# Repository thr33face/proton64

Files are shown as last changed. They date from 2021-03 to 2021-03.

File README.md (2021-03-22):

# Proton-64 - C64/VIC20 keyboard to USB conversion

A case designed to house a standard, unmodified C64 (or VIC20) keyboard and QMK Proton C. Keyboard is at a 9° angle.

Bottom plate has one hole to expose the Proton C's button for easy firmware updates without the need for key combos/macros.

The case is held together by 9 M2x5 screws.

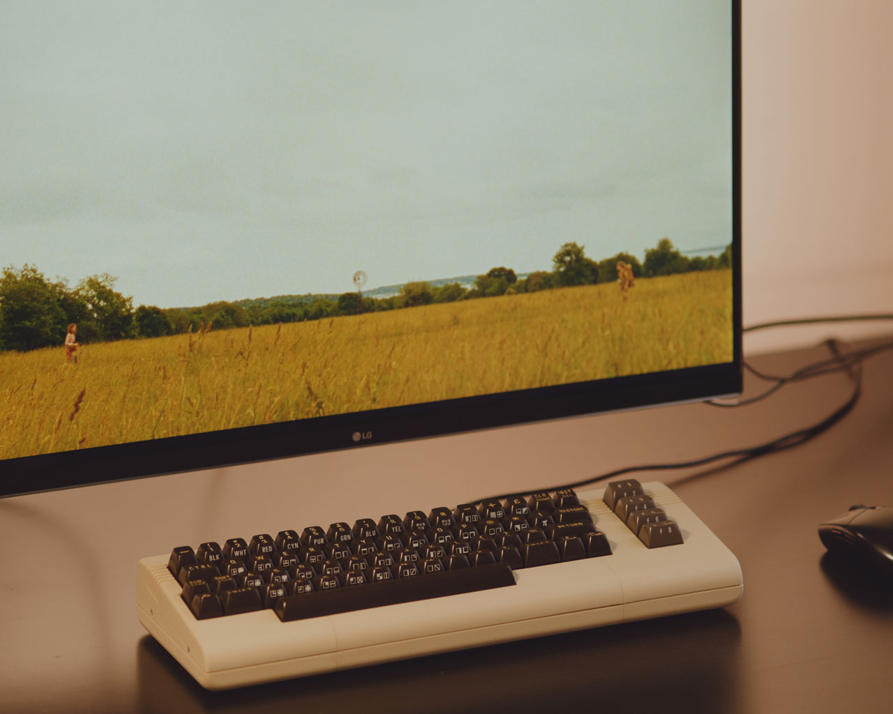
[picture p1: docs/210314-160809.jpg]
keyboard and monitor

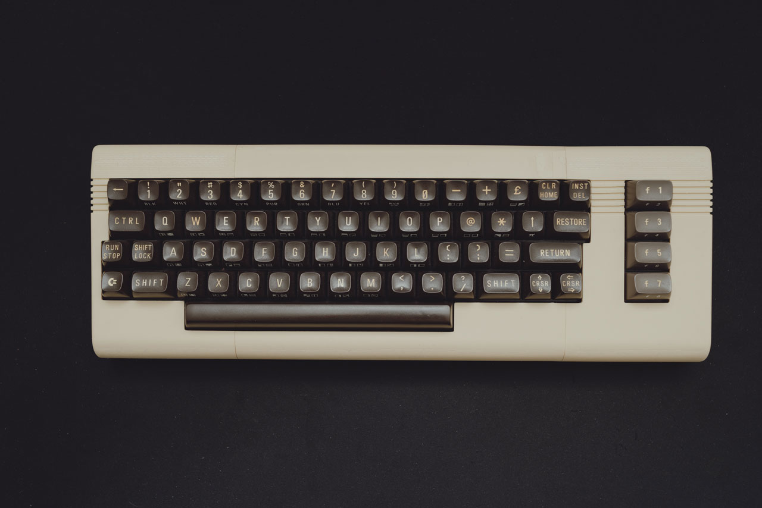
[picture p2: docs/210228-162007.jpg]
top shot


Depending on your printer and build size limitations you will have to cut the model into several pieces and join them somehow.
For my print I split the design by 3 horizontally and joined the pieces using CA-glue as well as 'welding' single layer PLA sheets over the joints. 

My recommendation is to add rubber feet to the 4 bottom corners.

Also, if you're not using a QMK Proton C you need to design your own IO-plate and modify the mounting/hold-down mechanism ('X' in bottom plate) to fit your specific controller. 

## Design goals ##
- no modifications to original keyboard
- capture design language of breadbin C64
- comfortable, usable angle without adjustment possibilities (original C64 wasn't adjustable)
- print in material simulating UV damage

## Some info about the print/build ##
**Modeled in:** Fusion 360

**Slicer:** Cura

**Printer:** Creality Ender 3 Pro (stock) @ 0.12mm

**Material:** Midori PLA (Beige RAL1014) - 200 °C

**Post Processing:** sanding and matte clear coat

**C64 keyboard manuf. year:** 1984

## Layers compared to original layout ##
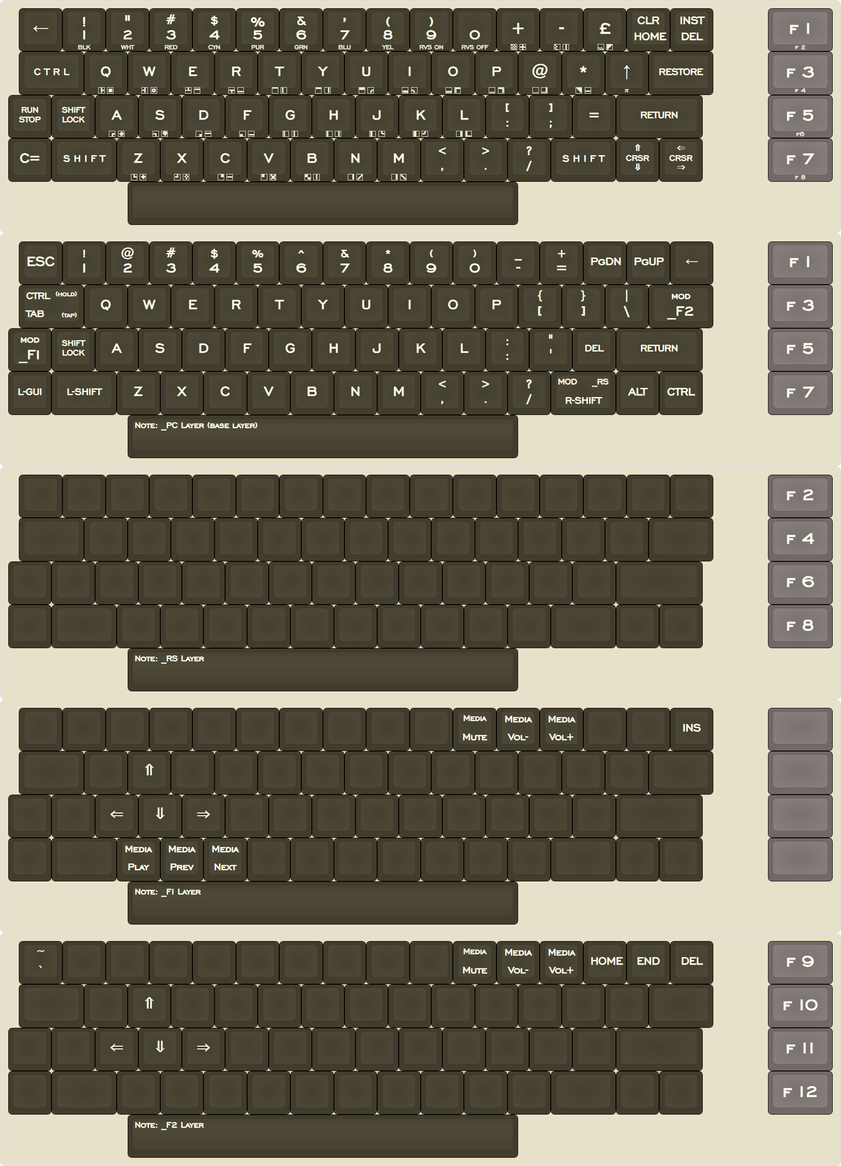
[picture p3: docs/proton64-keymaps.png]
keymap and layers


## More images ##
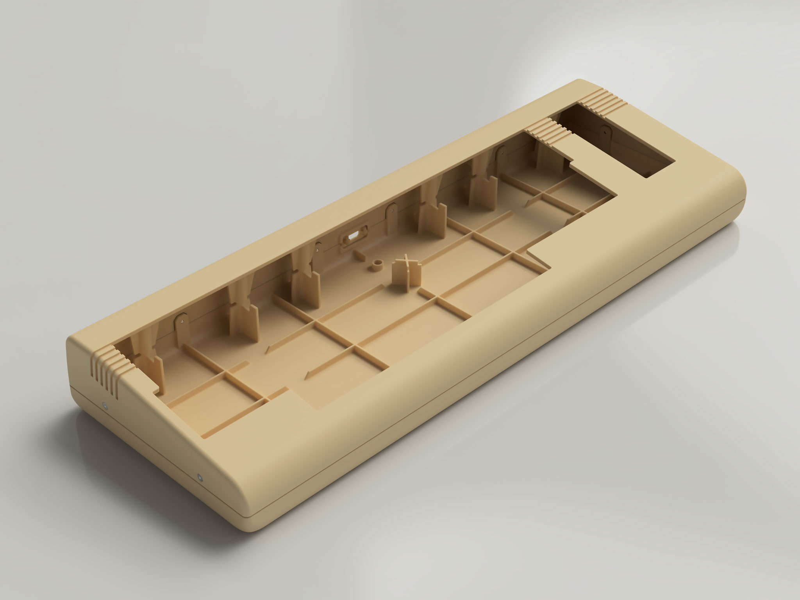
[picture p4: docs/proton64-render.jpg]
cura render

_Fusion360 render_

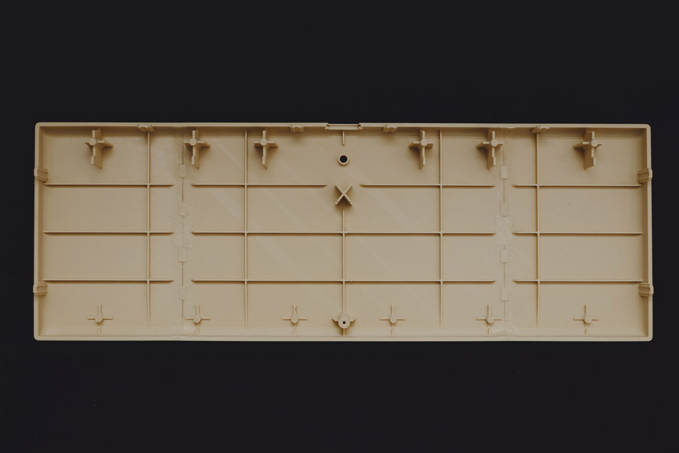
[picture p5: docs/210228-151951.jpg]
bottom case

_bottom case_

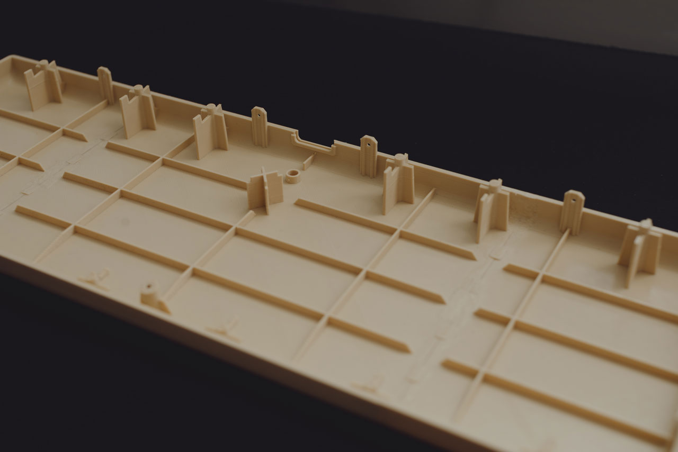
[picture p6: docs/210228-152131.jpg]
bottom case at an angle

_bottom case at an angle_

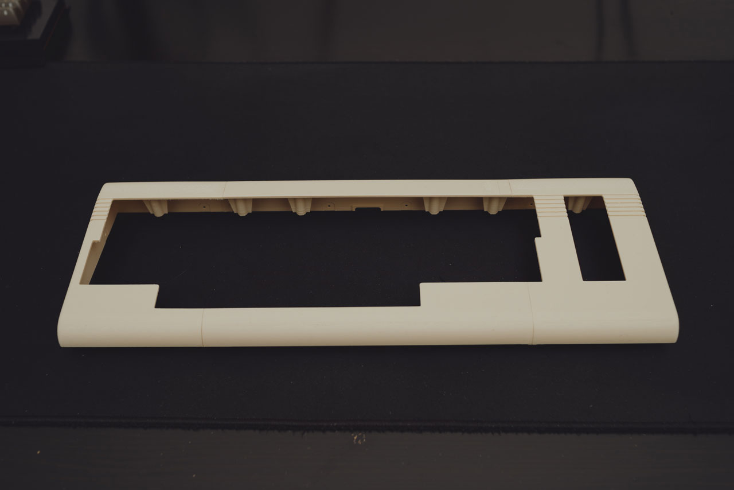
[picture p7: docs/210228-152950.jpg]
top case

_top case_

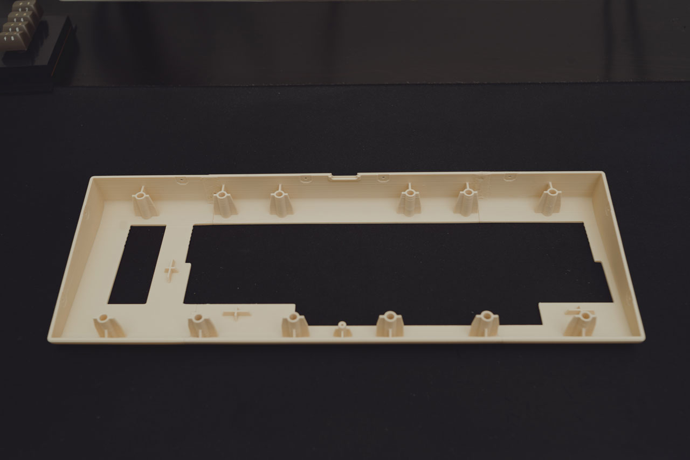
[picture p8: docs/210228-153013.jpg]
top case inside

_top case inside_

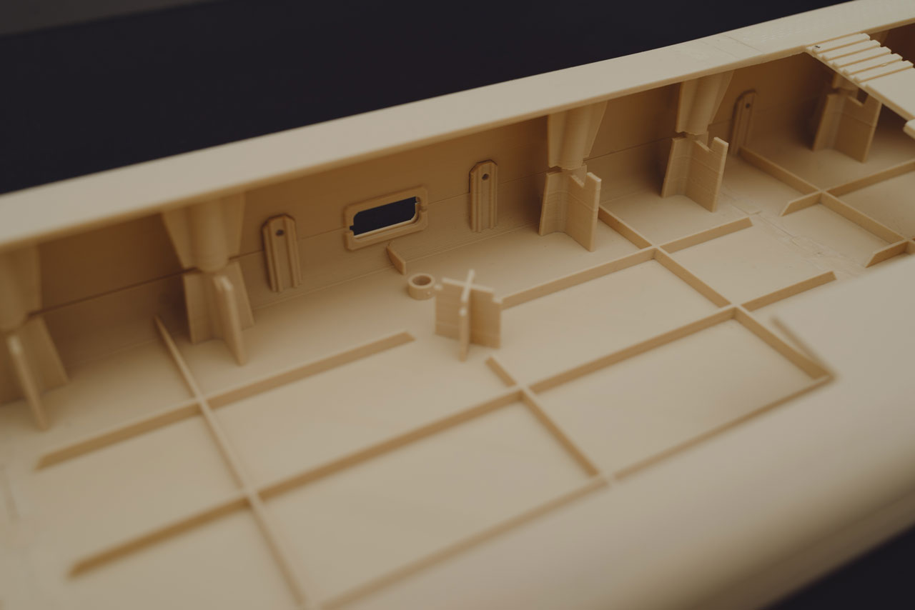
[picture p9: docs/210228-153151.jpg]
case joined

_case halves together_

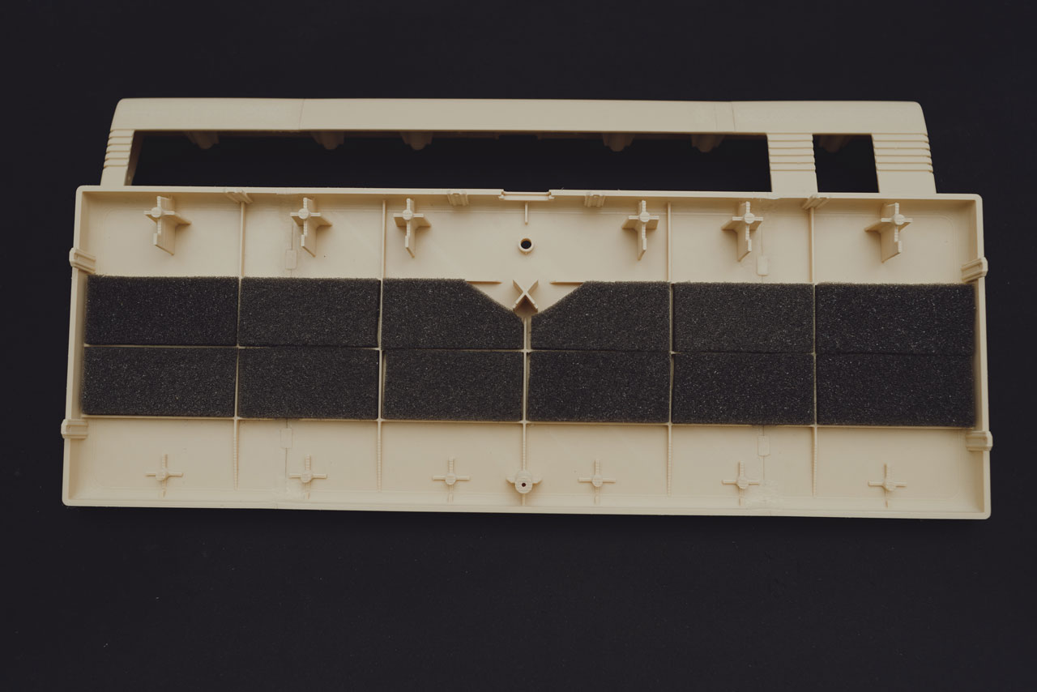
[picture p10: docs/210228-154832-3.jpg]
foam

_foam for noise dampening_

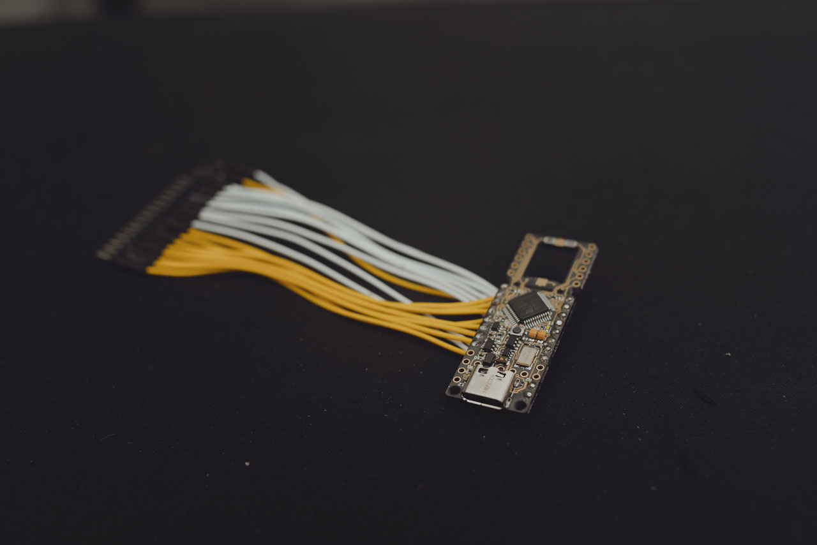
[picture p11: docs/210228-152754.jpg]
proton c wires

_proton c_

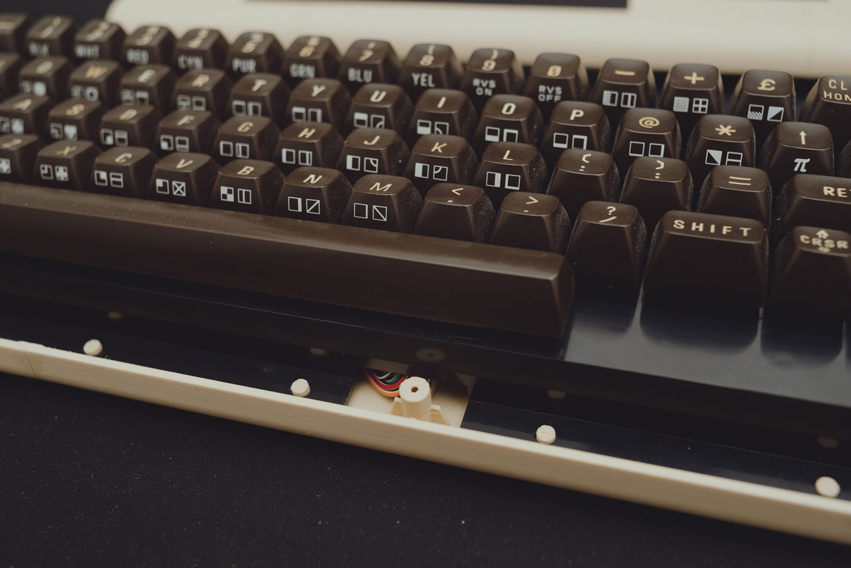
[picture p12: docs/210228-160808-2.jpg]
keyboard1

_keyboard detail_

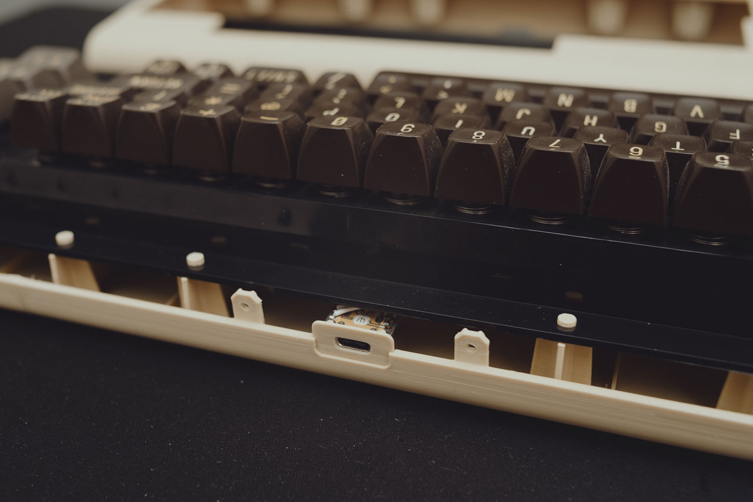
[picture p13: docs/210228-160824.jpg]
keyboard2

_keyboard detail_

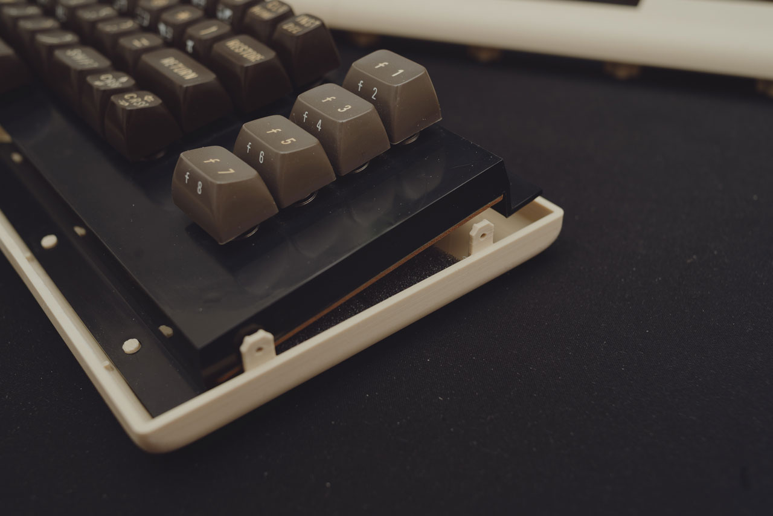
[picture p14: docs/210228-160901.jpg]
keyboard3

_keyboard detail_

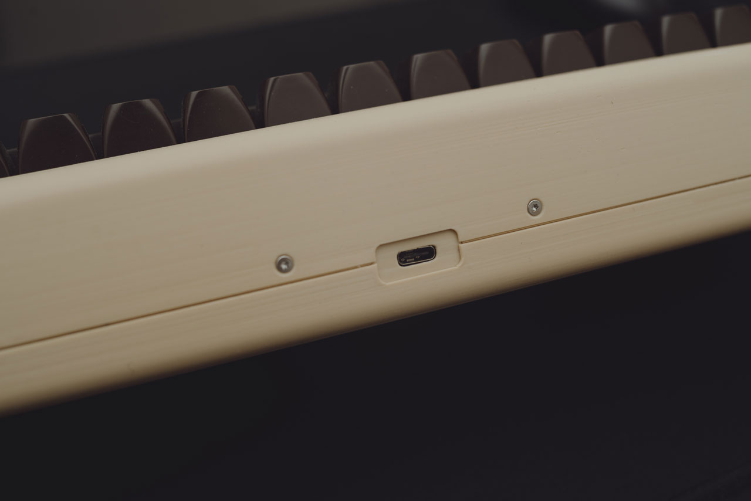
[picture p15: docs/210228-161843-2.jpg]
connector

_connector plate_

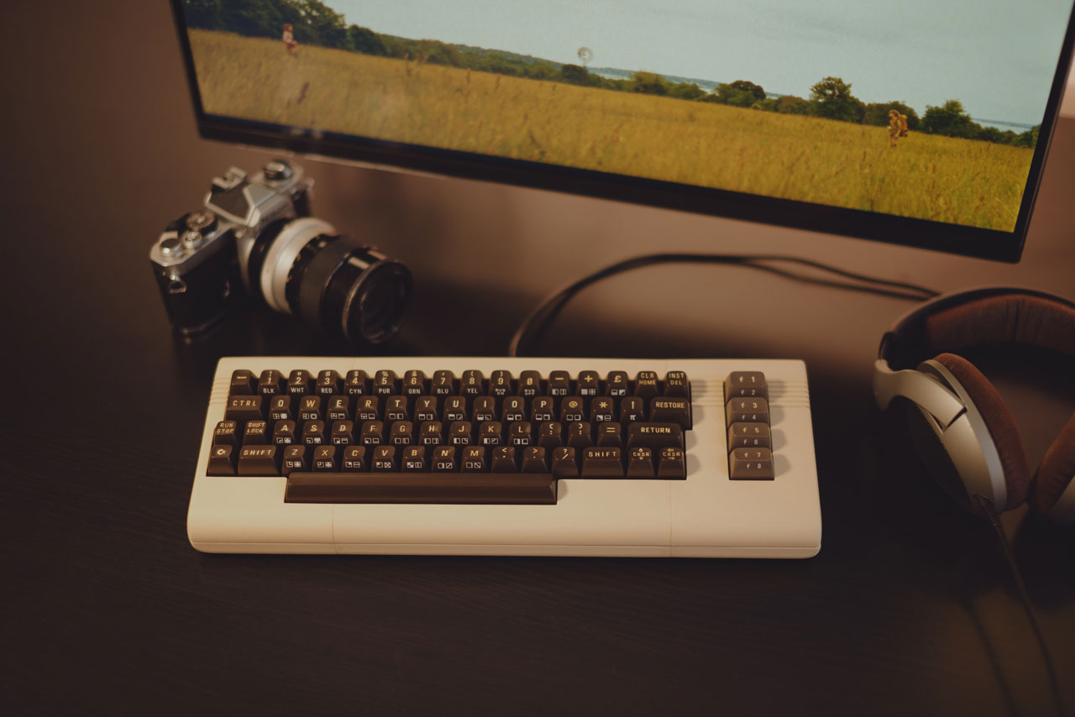
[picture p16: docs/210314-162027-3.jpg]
beauty shot

_on desk_

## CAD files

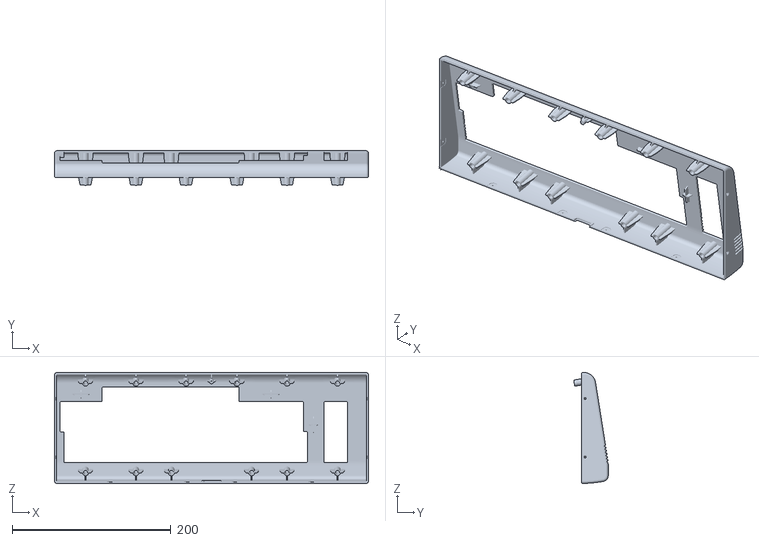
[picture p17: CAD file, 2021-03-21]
proton64-case-top.stl
395.0 x 43.5 x 139.7

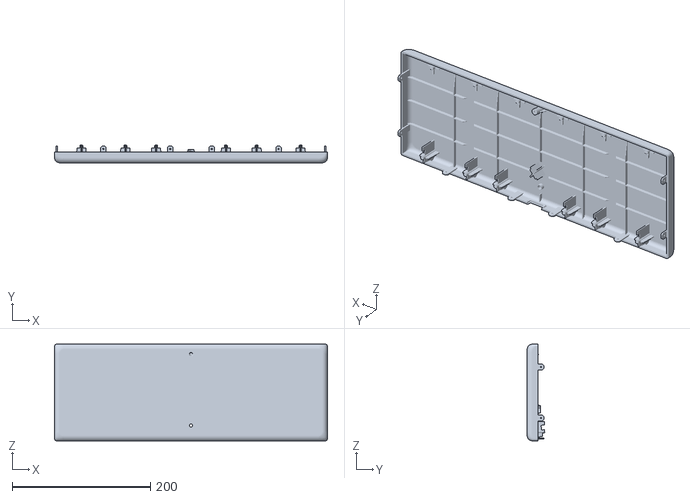
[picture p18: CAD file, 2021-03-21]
proton64-case-bottom.stl
395.0 x 25.6 x 139.7

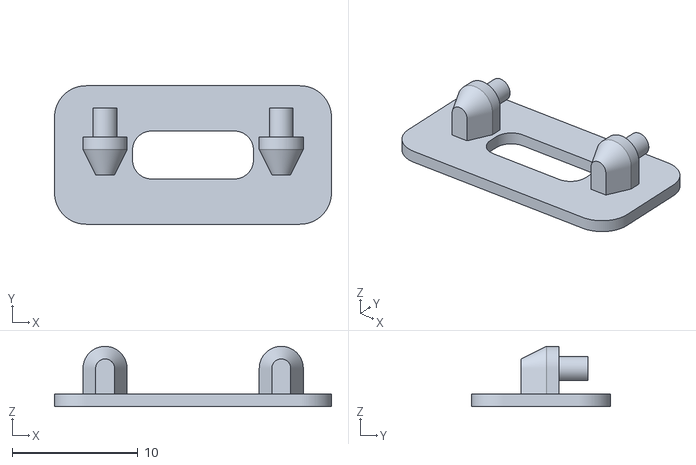
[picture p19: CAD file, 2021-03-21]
proton64-plate-protonc.stl
22.0 x 11.0 x 4.79
